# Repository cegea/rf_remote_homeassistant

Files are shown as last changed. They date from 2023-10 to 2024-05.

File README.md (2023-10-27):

# Remote RF for HomeAssistant
RF remote based on RP2040 and CC1101. For those sub-gigahertz remotes laying around. 

Opening the remote control reveals that it has the integrated HS2260A, which is a clone of the PT2260.

The protocol used in wireless communications is explained in the latter's datasheet. In this case being at the frequency 433.92 MHz.

The format of the transmitted message is as follows:

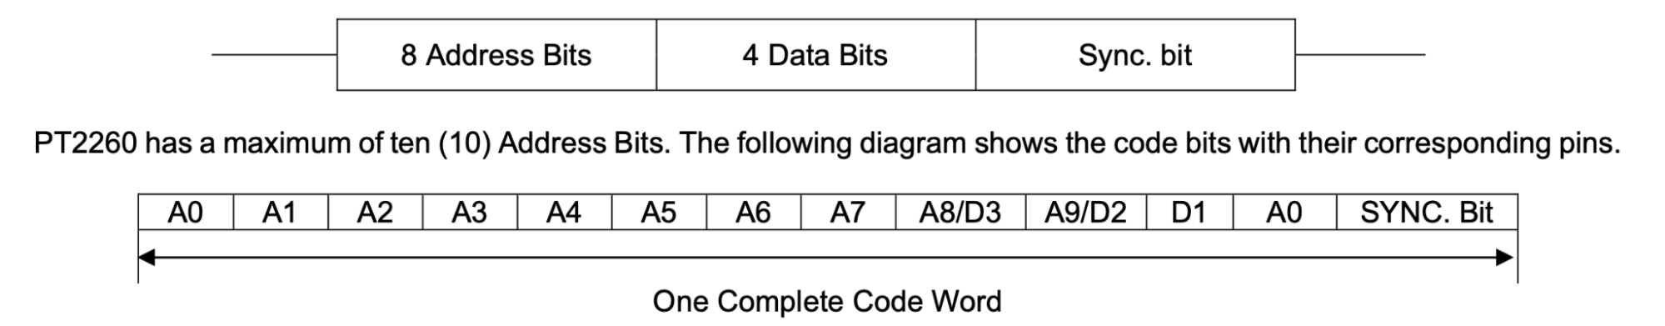
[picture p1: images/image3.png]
image_tooltip


As seen in the figure, the address is sent first, then the data and then a synchronization bit.

In the case of the command used in that case, the integrated one has the R4 termination, which indicates that it has 8 addressing bits, 4 data bits and one synchronization bit.

The symbolic representation of the address and data bits is according to the following figure:

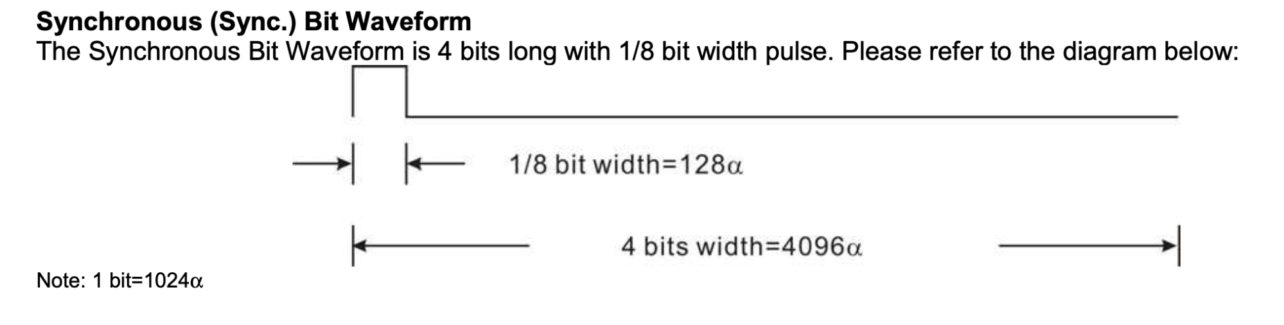
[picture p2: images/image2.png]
image_tooltip


The synchronization bit is as follows:

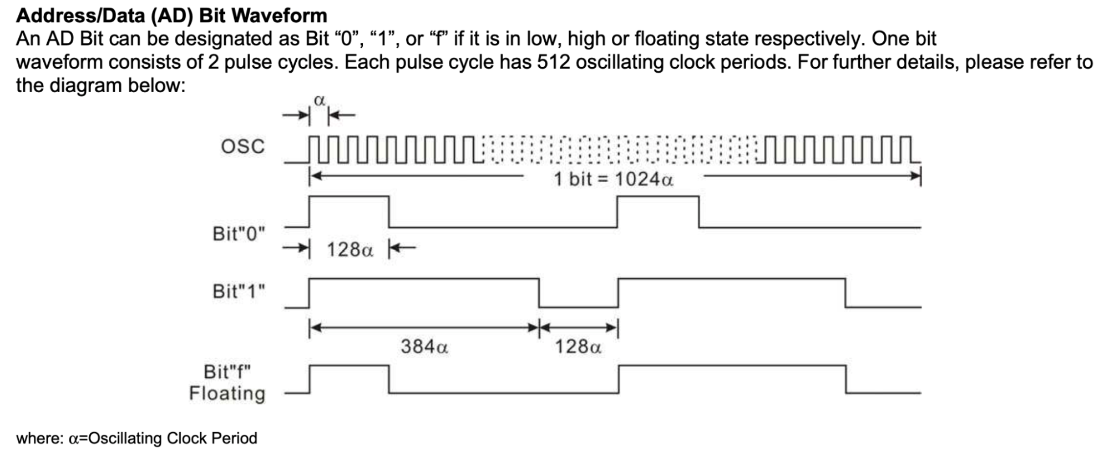
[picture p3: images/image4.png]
image_tooltip


# DECODING MESSAGES

Using URH ([https://github.com/jopohl/urh](https://github.com/jopohl/urh)) the messages sent for each of the two operating buttons on the controller are decoded:

Off Button:

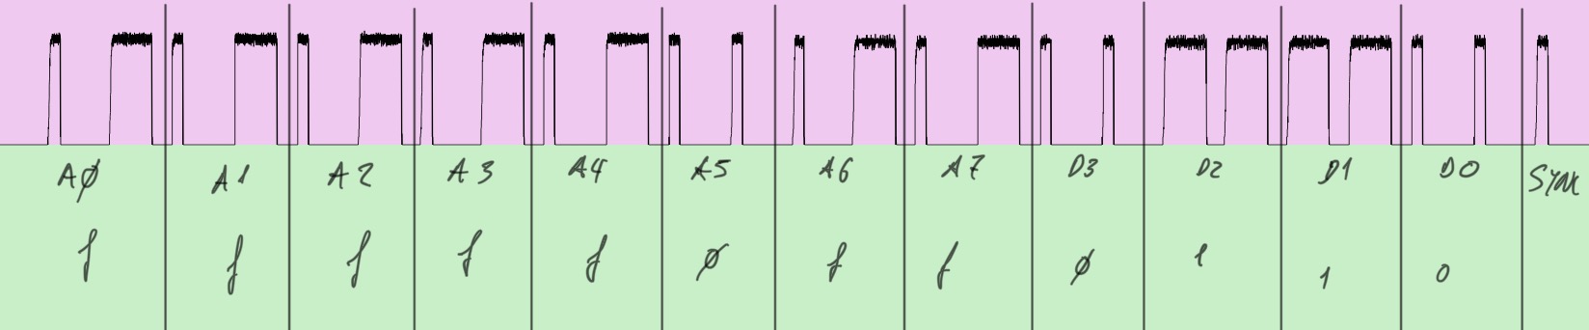
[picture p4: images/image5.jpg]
image_tooltip


On button:

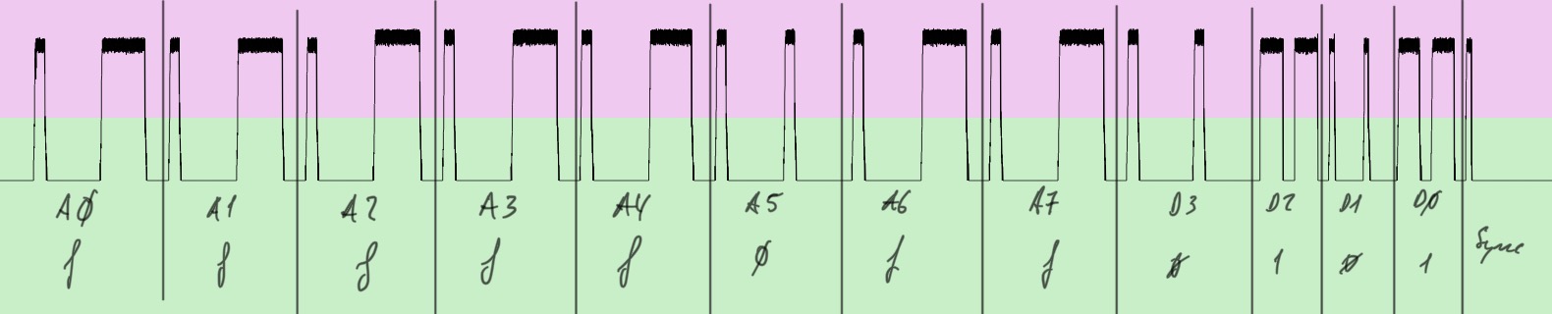
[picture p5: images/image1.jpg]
image_tooltip


The smallest width is about 300 us. Which corresponds to one eighth of the bit width. With which:

* ‘f’  → 10001110 → 0x8e
* ‘0’ → 10001000 → 0x88
* ‘1’ → 11101110 → 0xee
* sync → 10000000 → 0x80

The sequences would be as follows (in hex):

<table>
  <tr>
   <td>A0
   </td>
   <td>A1
   </td>
   <td>A2
   </td>
   <td>A3
   </td>
   <td>A4
   </td>
   <td>A5
   </td>
   <td>A6
   </td>
   <td>A7
   </td>
   <td>D3
   </td>
   <td>D2
   </td>
   <td>D1
   </td>
   <td>D0
   </td>
   <td>SYN
   </td>
  </tr>
  <tr>
   <td colspan="13" >Off Button
   </td>
  </tr>
  <tr>
   <td>8e
   </td>
   <td>8e
   </td>
   <td>8e
   </td>
   <td>8e
   </td>
   <td>8e
   </td>
   <td>88
   </td>
   <td>8e
   </td>
   <td>8e
   </td>
   <td>88
   </td>
   <td>ee
   </td>
   <td>ee
   </td>
   <td>88
   </td>
   <td>80
   </td>
  </tr>
  <tr>
   <td colspan="13" >On button
   </td>
  </tr>
  <tr>
   <td>8e
   </td>
   <td>8e
   </td>
   <td>8e
   </td>
   <td>8e
   </td>
   <td>8e
   </td>
   <td>88
   </td>
   <td>8e
   </td>
   <td>8e
   </td>
   <td>88
   </td>
   <td>ee
   </td>
   <td>88
   </td>
   <td>ee
   </td>
   <td>80
   </td>
  </tr>
</table>

The silences between messages are approximately 5 ms, which with a resolution of 300 us corresponds to 16.6 zeros in binary or 4 bytes with a value of 0 (more are left for convenience).

# CC1101-TOOL

All credit goes to **Alam Laboda** for this amazing work at: https://github.com/mcore1976/cc1101-tool.

To configure and use this tool, the following commands are used:

setmodulation 2

ON button

Repeatedly:

addraw 0000000008e8e8e8e8e888e8e88ee88ee8000000

OOFF button

Repeatedly:

addraw 0000000008e8e8e8e8e888e8e88eeee888000000

playraw 300

# RP2040 MQTT

All credit goes to **Khoi Hoang** for this amazing work at: https://github.com/khoih-prog/AsyncMqttClient_Generic

Use of the example to connect to a mqtt topic and parse the commands as if a serial interface where used. This is implemented with the multicore capabilities of the RP2040.

# RP2040 Multicore and FIFO

All credit goes to **Earle F. Philhower, III** for this amazing work at: https://github.com/earlephilhower/arduino-pico

I´ve made an example to parse a pointer addres instead of whole commands to ease of use here (I might create a pull request): https://github.com/cegea/arduino-pico/blob/example/multicore_fifo/libraries/rp2040/examples/MulticoreFIFO/MulticoreFIFO.ino

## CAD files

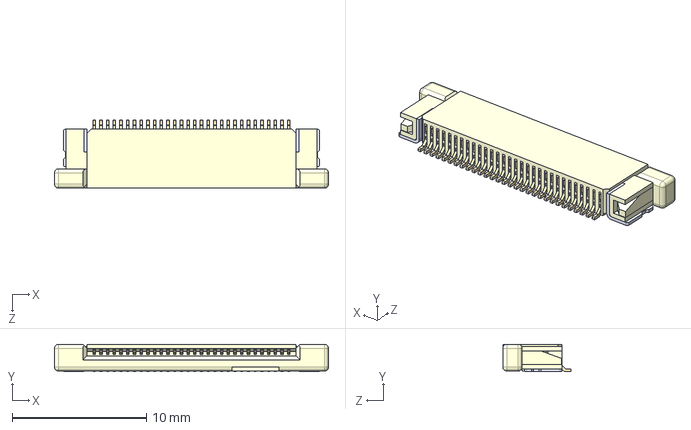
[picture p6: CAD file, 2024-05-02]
remote/3-1734839-0/3-1734839-0.step
20.4 x 2.05 x 5.10 mm

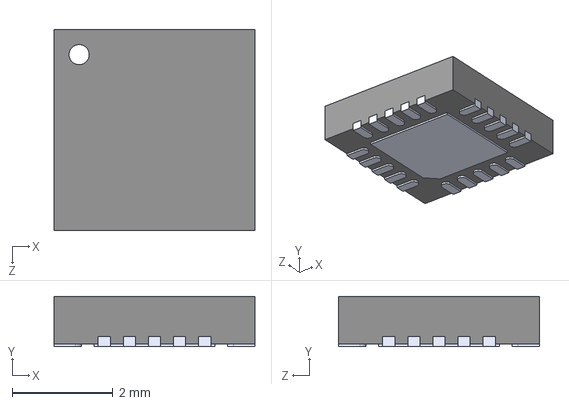
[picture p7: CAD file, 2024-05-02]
remote/CC1101RGP/CC1101RGP.step
4.00 x 1.00 x 4.00 mm

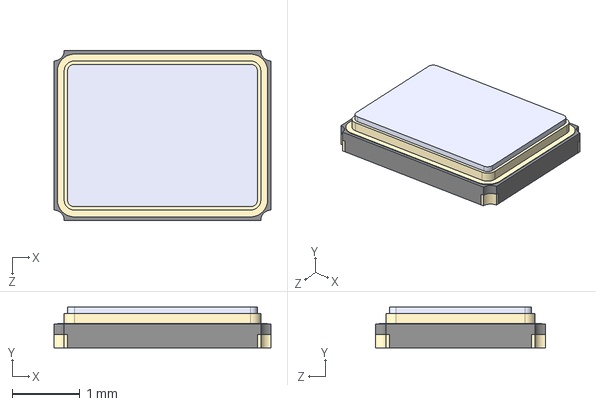
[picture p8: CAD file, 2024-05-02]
remote/NX3225GA-26MHZ-TI/NX3225GA-26MHZ-TI.step
3.20 x 0.6 x 2.50 mm

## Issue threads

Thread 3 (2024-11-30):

Device keeps trying to reconnect even if it has the credentials

cegea, 2024-11-30:
The device fails to connect to wifi or disconnects, and starts the provisioning procedure

Closed 2024-12-23.

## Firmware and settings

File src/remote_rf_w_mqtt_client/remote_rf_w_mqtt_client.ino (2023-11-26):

#include <AsyncMqtt_Generic.h>
#include "remote_rf_w_mqtt_client.h"

//Declare remoteRF

RemoteRF remote(SCK, MISO, MOSI, SS, GDO0, GDO2);

// Declare remotes:
Remote_t remoteControlArray[] = {
    {"CHISME_ON", F433, MODULATION_ASK_OOK, CODE_CHISME_ON, 4, 300},
    {"CHISME_OFF", F433, MODULATION_ASK_OOK, CODE_CHISME_OFF, 4, 300},
    {"INT_DOOR", F868, MODULATION_ASK_OOK, CODE_INTERIOR_DOOR, 8, 215},
    {"EXT_DOOR", F868, MODULATION_ASK_OOK, CODE_EXTERIOR_DOOR, 8, 215}
};

// Get the size of the remoteControlArray
size_t remoteControlArraySize = sizeof(remoteControlArray) / sizeof(remoteControlArray[0]);

void setup1() {
  remote.cc1101initialize();
}

void loop1() {
  remote.processIncomingCommands(remoteControlArray,remoteControlArraySize);
}

void setup() {
  setup_mqtt();
}

void loop() {
  loop_mqtt();
}

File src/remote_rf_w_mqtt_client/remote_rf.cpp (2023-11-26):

#include "remote_rf.h"
#include <SPI.h>

// Portions of this code are based on the cc1101-tool repository by mcore1976.
// Repository: https://github.com/mcore1976/cc1101-tool

RemoteRF::RemoteRF(uint8_t sck, uint8_t miso, uint8_t mosi, uint8_t ss, uint8_t gdo0, uint8_t gdo2){
    _sck =  sck;
    _miso = miso;
    _mosi = mosi;
    _ss =  ss;
    _gdo0 = gdo0;
    _gdo2 = gdo2;
}

void RemoteRF::cc1101initialize() {
    // initializing library with custom pins selected

    SPI.setRX(_miso);
    SPI.setTX(_mosi);
    SPI.setSCK(_sck);
    SPI.setCS(_ss);

    gpio_init(_gdo0);
    gpio_set_dir(_gdo0, GPIO_OUT);

     ELECHOUSE_cc1101.setSpiPin(_sck, _miso, _mosi, _ss);
     ELECHOUSE_cc1101.setGDO(_gdo0, _gdo2);

    // Main part to tune CC1101 with proper frequency, modulation and encoding    
    ELECHOUSE_cc1101.Init();                // must be set to initialize the cc1101!
    ELECHOUSE_cc1101.setGDO0(_gdo0);         // set lib internal gdo pin (gdo0). Gdo2 not use for this example.
    ELECHOUSE_cc1101.setCCMode(1);          // set config for internal transmission mode. value 0 is for RAW recording/replaying
    ELECHOUSE_cc1101.setModulation(2);      // set modulation mode. 0 = 2-FSK, 1 = GFSK, 2 = ASK/OOK, 3 = 4-FSK, 4 = MSK.
    ELECHOUSE_cc1101.setMHZ(433.92);        // Here you can set your basic frequency. The lib calculates the frequency automatically (default = 433.92).The cc1101 can: 300-348 MHZ, 387-464MHZ and 779-928MHZ. Read More info from datasheet.
    ELECHOUSE_cc1101.setDeviation(47.60);   // Set the Frequency deviation in kHz. Value from 1.58 to 380.85. Default is 47.60 kHz.
    ELECHOUSE_cc1101.setChannel(0);         // Set the Channelnumber from 0 to 255. Default is cahnnel 0.
    ELECHOUSE_cc1101.setChsp(199.95);       // The channel spacing is multiplied by the channel number CHAN and added to the base frequency in kHz. Value from 25.39 to 405.45. Default is 199.95 kHz.
    ELECHOUSE_cc1101.setRxBW(812.50);       // Set the Receive Bandwidth in kHz. Value from 58.03 to 812.50. Default is 812.50 kHz.
    ELECHOUSE_cc1101.setDRate(9.6);         // Set the Data Rate in kBaud. Value from 0.02 to 1621.83. Default is 99.97 kBaud!
    ELECHOUSE_cc1101.setPA(10);             // Set TxPower. The following settings are possible depending on the frequency band.  (-30  -20  -15  -10  -6    0    5    7    10   11   12) Default is max!
    ELECHOUSE_cc1101.setSyncMode(2);        // Combined sync-word qualifier mode. 0 = No preamble/sync. 1 = 16 sync word bits detected. 2 = 16/16 sync word bits detected. 3 = 30/32 sync word bits detected. 4 = No preamble/sync, carrier-sense above threshold. 5 = 15/16 + carrier-sense above threshold. 6 = 16/16 + carrier-sense above threshold. 7 = 30/32 + carrier-sense above threshold.
    ELECHOUSE_cc1101.setSyncWord(211, 145); // Set sync word. Must be the same for the transmitter and receiver. Default is 211,145 (Syncword high, Syncword low)
    ELECHOUSE_cc1101.setAdrChk(0);          // Controls address check configuration of received packages. 0 = No address check. 1 = Address check, no broadcast. 2 = Address check and 0 (0x00) broadcast. 3 = Address check and 0 (0x00) and 255 (0xFF) broadcast.
    ELECHOUSE_cc1101.setAddr(0);            // Address used for packet filtration. Optional broadcast addresses are 0 (0x00) and 255 (0xFF).
    ELECHOUSE_cc1101.setWhiteData(0);       // Turn data whitening on / off. 0 = Whitening off. 1 = Whitening on.
    ELECHOUSE_cc1101.setPktFormat(0);       // Format of RX and TX data. 0 = Normal mode, use FIFOs for RX and TX. 1 = Synchronous serial mode, Data in on GDO0 and data out on either of the GDOx pins. 2 = Random TX mode; sends random data using PN9 generator. Used for test. Works as normal mode, setting 0 (00), in RX. 3 = Asynchronous serial mode, Data in on GDO0 and data out on either of the GDOx pins.
    ELECHOUSE_cc1101.setLengthConfig(1);    // 0 = Fixed packet length mode. 1 = Variable packet length mode. 2 = Infinite packet length mode. 3 = Reserved
    ELECHOUSE_cc1101.setPacketLength(0);    // Indicates the packet length when fixed packet length mode is enabled. If variable packet length mode is used, this value indicates the maximum packet length allowed.
    ELECHOUSE_cc1101.setCrc(0);             // 1 = CRC calculation in TX and CRC check in RX enabled. 0 = CRC disabled for TX and RX.
    ELECHOUSE_cc1101.setCRC_AF(0);          // Enable automatic flush of RX FIFO when CRC is not OK. This requires that only one packet is in the RXIFIFO and that packet length is limited to the RX FIFO size.
    ELECHOUSE_cc1101.setDcFilterOff(0);     // Disable digital DC blocking filter before demodulator. Only for data rates ≤ 250 kBaud The recommended IF frequency changes when the DC blocking is disabled. 1 = Disable (current optimized). 0 = Enable (better sensitivity).
    ELECHOUSE_cc1101.setManchester(0);      // Enables Manchester encoding/decoding. 0 = Disable. 1 = Enable.
    ELECHOUSE_cc1101.setFEC(0);             // Enable Forward Error Correction (FEC) with interleaving for packet payload (Only supported for fixed packet length mode. 0 = Disable. 1 = Enable.
    ELECHOUSE_cc1101.setPRE(0);             // Sets the minimum number of preamble bytes to be transmitted. Values: 0 : 2, 1 : 3, 2 : 4, 3 : 6, 4 : 8, 5 : 12, 6 : 16, 7 : 24
    ELECHOUSE_cc1101.setPQT(0);             // Preamble quality estimator threshold. The preamble quality estimator increases an internal counter by one each time a bit is received that is different from the previous bit, and decreases the counter by 8 each time a bit is received that is the same as the last bit. A threshold of 4∙PQT for this counter is used to gate sync word detection. When PQT=0 a sync word is always accepted.
    ELECHOUSE_cc1101.setAppendStatus(0);    // When enabled, two status bytes will be appended to the payload of the packet. The status bytes contain RSSI and LQI values, as well as CRC OK.
}

void RemoteRF::configureFrequency(float frequency) {
  // Configure the frequency
  ELECHOUSE_cc1101.setMHZ(frequency);
  
  #ifdef DEBUG0
    Serial.print("Configuring frequency: ");
    Serial.print(frequency, 2); // Print the frequency with 2 decimal places
    Serial.println(" MHz");
  #endif
}

void RemoteRF::setModulation(byte modulationMode) {
  ELECHOUSE_cc1101.setModulation(modulationMode);
  
  #ifdef DEBUG0
    Serial.print("Setting modulation mode: ");
    Serial.println(modulationMode);
  #endif
}
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

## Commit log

2023-11-26 Remove unnecessary prints
2024-05-02 Add initial sch
    [3-1734839-0.step, CC1101RGP.step, NX3225GA-26MHZ-TI.step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]
2024-07-19 Archivado de versión Kicad 7.0
